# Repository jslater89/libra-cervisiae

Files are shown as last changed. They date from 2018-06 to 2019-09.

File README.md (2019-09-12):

# Libra Cervisiae
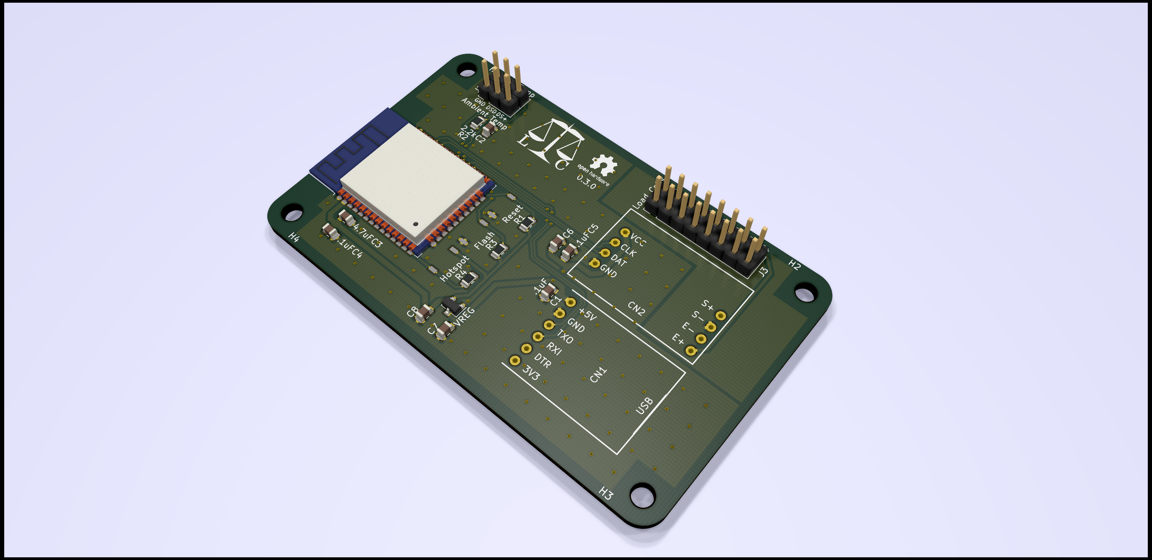
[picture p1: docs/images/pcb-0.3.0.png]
pcb


Libra Cervisiae is an ESP8266-powered microcontroller for reading output from a high-precision scale, used to weigh beer to measure the progress of its fermentation.

Development updates can be found at the project's [github pages site](https://jslater89.github.io/libra-cervisiae).

## History
Libra Cervisiae used to be Pendulum, which was itself once a tilting hydrometer (abandoned for patent reasons) and once a weigh-a-sinker hydrometer (abandoned for DIY difficulty reasons).

Libra Cervisiae has its root in experiments done in the 1990s on measuring fermentation progress by CO2 production, and more recent experiments done by forumgoers at [Homebrewtalk](https://www.homebrewtalk.com/forum/threads/estimating-alcohol-by-total-weight-during-fermentation.265716/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) and [Hobbybrouwen.nl](https://www.hobbybrouwen.nl/forum/index.php/topic,35958.0.html).

## Design
Libra Cervisiae is a microcontroller and PCB project. The project is designed with easy DIY in mind, and as such, the PCB uses large, easy-to-solder surface mount components, as well as breakout boards for the major, non-ESP8266 integrated circuits.

The project as specified here includes building a scale of your own, but the microcontroller's design ought to allow for hacking existing scales of the correct capacity, too.

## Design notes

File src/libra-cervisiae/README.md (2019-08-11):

## Libra Cervisiae
Source code for ESP8266 modules. Eventually it might support general Arduinos, through clever defines and whatnot. Today is not that day.

## Required Libraries
* ArduinoJson 5.13.2 (included in repository)
* [Arduino ESP8266](https://github.com/esp8266/Arduino)
* [DoubleMatrixMath](https://github.com/jslater89/DoubleMatrixMath)
* [HX711](https://github.com/bogde/HX711)
* [OneWire](https://github.com/PaulStoffregen/OneWire)
* [DallasTemperature](https://github.com/milesburton/Arduino-Temperature-Control-Library)
* [DoubleResetDetector](https://github.com/datacute/DoubleResetDetector)

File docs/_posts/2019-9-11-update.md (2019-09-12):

---
layout: post
title: PCB version 0.3.0 coming soon
---

assembled

Redesigning the board for the ESP32 was a good chance to make some larger design changes. The biggest, most obvious one is the rounded corners, along with the increase in size. This is to fit a specification, the Sick of Beige 80mm x 49mm board, for which I had hoped cases would be available. It appears they are not, but at least it's a spec I can design to.

This is the canonical simple 8049 case:

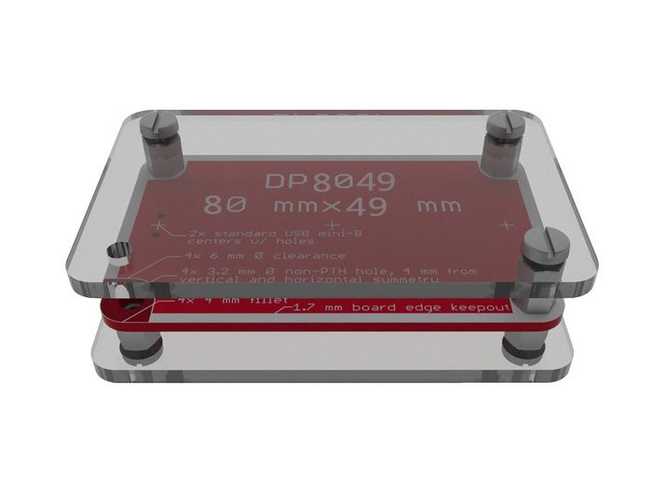
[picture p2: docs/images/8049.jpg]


Seeed Studios used to sell them for $3, but they're out of stock now. I'm sure I could find someone to knock out the top and bottom plates for me; it's not at all a complicated job.

The next design change flows out of a desire to support cases in the future: 90-degree pin headers (not pictured). The temperature sensor pin headers move to the same edge of the board as the load cell headers.

I added a third button to force a boot into hotspot mode, rather than doing a double reset detector. The only way to do that on the ESP32 would be to use the internal flash, and I don't want to do any more writes to the flash memory than I absolutely have to.

Lastly, I changed the trace routing somewhat, favoring straighter lines, smaller runs on the bottom layer of the board, and thicker power traces.

I expect this revision of the board to be the basis for 1.0.0. A future 2.0.0 might eliminate the breakout-boards-on-pin-headers paradigm altogether and go full surface mount. That would open the door to full assembly in one of the overseas shops, since there's no longer a tricky two-step process. It would close the door to all but the most dedicated hobbyists, however; it may be possible to keep both versions of the board around at the same time.

A final revision might be to use the Raspberry Pi's board dimensions instead, which would then open up a whole world of cases. It is notably less simple than the 8049 spec, however.

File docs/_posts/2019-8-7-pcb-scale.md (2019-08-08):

---
layout: post
title: A happy PCB update!
---

It's been a long time since I had real progress to report, but here we are: an assembled Libra Cervisiae PCB is actually reading from a load cell.

The problem is not one of design, at least for the single load cell case, but rather one of connectors. The latest revision of PCB uses standard 2.54mm Dupont connectors to attach the load cells. The load cells, however, come with very thin wires, and don't make good contact inside the terminal. I expect this can be solved by stripping a little more of the wire and folding the exposed part under the insulator before crimping. If that doesn't work, I can always try putting a little dab of solder in the terminal.

To verify it was the connectors after all, I ensured that the load cell was making good contact by getting the load cell wires in direct contact with the openings on some Dupont jumpers:



The PCB is performing well—using big pours for the excitation and signal grounds, and paying attention to return paths, seems to have made the miniature scale pretty interference-free. It's precise to within about a gram, or about 150 nanovolts. Fun.

Slightly less fun is that there are a few grams' worth of error depending on which of the four hookups the load cell is attached to. It might have to do with traces of slightly different length and therefore slightly different resistance. I might fatten the + traces up a bit to try to mitigate that, but at the same time, the use case here doesn't require perfect accuracy every time. We are, after all, basically integrating for better accuracy over the entire course of fermentation.

Anyway, having sussed out the issue, I can keep on pushing the design forward and get back to work on the full-size scale.

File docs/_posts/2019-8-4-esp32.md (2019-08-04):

---
layout: post
title: Getting back to work
---

I haven't done much on this project for almost a year—that's life, sometimes. I was planning on returning to it this summer anyway, but that return was somewhat delayed by some projects around the house, including (helpfully for this project) moving brewing operations from my friend's kitchen to my basement.

The latest piece of news is that I'm planning on switching from the ESP8266 to the ESP32. The big upside to this is that the ESP32 has enough memory both to load the scale program and do SSL requests, unlike the ESP8266, which means that the ESP32 version will be able to log updates directly to Google Sheets without an intermediary. The circuit design is a little simpler, too—the reference circuit indicates fewer pullup resistors, because more of them are on the module (the ESP-32-WROOM or pin-compatible ESP-32S). In exchange, it's a bit harder to solder—it's about the same size, but has more pins with finer pitch.

An ESP32 development board and a few bare modules are on their way from China. Once they arrive (September or so?) I can start on the process of updating the software and ensuring my board design is correct. In the interim, I hope to use the ESP8266 boards I have, along with the one-cell test scale I used last summer, to start isolating the problems with the full-size scale, which could be one of several things:

1. Bad crimps on the connectors on the load cell wires.
2. Bad soldering on the pin headers on the board.
3. Bad load cells in the full-size scale.
4. Poorly matched load cells on the full-size scale, such that their output is invalid when they're wired in parallel.
5. Incorrect understanding of how to wire load cells in parallel. I'm using four-wire full-bridge sensors, and simply connecting the excitation and sense lines in parallel is supposed to be enough, as far as I can tell, but I could be wrong.

Updates to come as I make progress.

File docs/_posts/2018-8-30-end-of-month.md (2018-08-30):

---
layout: post
title: PCB assembly and other development news
---

assembled

There you have it! An assembled Libra Cervisiae PCB.

After some head-scratching and trial and error, it even works—it's sitting on the table next to me, running the Libra Cervisiae software and playing hotspot. There are some caveats. We'll come back to those.

There was a good bit of trial and error involved in getting the build settings right, but I have a good set of them now. I'll be sure to add those to the manual when I get around to it.

I upgraded my Arduino IDE to 1.8.6, and upgraded the project structure to be one Arduino sketch file (libra-cervisiae.ino), and a bunch of C++-compatible headers and source files. This is better for organization, permitting actual, proper control of variable scope and whatnot, and doesn't depend on arcane features of the Arduino IDE pre-build munge-tabs-together step. Improvements all around.

There are several problems to take care of. First, I had some issues with booting into UART download mode, which went away after a bit of reworking. Either I had bad solder joins or a short between GPIO15 and GPIO2 (fixed by adding some solder and hitting it with the hot air rework thing to make sure it reflowed correctly), or the 10k pulldown resistor was too large. (I swapped in a 1.2k resistor at the same time as I did the other rework.) I can verify which one it was by switching back to the 10kohm resistor, which is planned for this evening. I'd like to keep the 10k resistor, because that's one fewer distinct part to include.

I had some trouble with resets until I checked the schematic and saw that I had the scale's clock and data pins backward, which caused hangs and resets. Now that that's squared away, I'm on to other troubles with sensors, namely that the on-board temperature sensor isn't showing up, and that there seems to be quite a bit of noise in the weight sensor readings, and that it looks to be drifting fairly substantially over time as I check back in on the output through the course of my work day, from about 1650 up to 1950 now in raw output. It may have to do with static, capacitive coupling, or board heating, or possibly noise from the CP2102 board. It's hard to say without an oscilloscope.

For the temperature sensor stuff, I have a few things to try—verify a temperature sensor on a breadboard, try plugging one in to the socket on the PCB, use a stronger pullup resistor. For the weight sensor, that's a bit trickier. I'll probably add a second, smaller filtering capacitor next to the HX711, and throw in more filtering near the ESP8266 for good measure. I may also add an analog ground plane to the bottom of the board on the corner with the load cell, to allow for a cleaner ground for the load cell's S- lines. In doing so, I can probably also eliminate vias altogether on that part of the board, and may be able to match trace length a little more closely.

Anyway, that's the state of things. Still moving forward, but PCB changes and debugging are harder and slower than doing it all on breadboards with pre-built boards. Stay tuned.

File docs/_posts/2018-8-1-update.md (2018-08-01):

---
layout: post
title: Update and further testing results
---

I've been hard at work the last few days. Let's take a look at what I've been doing.

### Development update: front end
Libra Cervisiae requires a more complicated user-facing interface than Pendulum did. In particular, calibration is more complicated, and the use of two temperature sensors (one for the wort, one for the ambient temperature) means there has to be some mechanism to select between them.

load cell calibration

To calibrate the scale, you start by hitting the tare button with nothing on the platform. That sets the zero point, as you'd expect it to. After that, you place a known mass on the platform, enter its weight in grams, and hit the calibrate button. That sets the scale factor, by which the raw reading is divided to obtain the output in grams.

Both tare and calibration have a seconds box; that determines over how long the value is averaged. 10 seconds seems like a good middle ground between speed and accuracy. Up to 30 seconds is supported.

temperature selection

The DS18xxx series of sensors have factory-set 64-bit device addresses, and can be connected in parallel on the same bus. Setting a wort sensor and board sensor allows me to provide accurate wort temperatures and also accurate ambient temperatures to correct the load cell output (if needed; see later on for that).

### Development update: back end
On the non-user-facing front, I've completed and committed a first pass at using Karl Balling's findings to interpret the scale's output. In 1843, that august German scientist determined that fermenting one gram of sugar yields 48.39% alcohol, 46.27% carbon dioxide, and 5.32% yeast biomass.

So, what we do is save the starting mass and the starting gravity when starting a batch. With the starting mass, we can determine the weight loss, and with the weight loss, we can determine the amount of alcohol produced. Since we're measuring the current mass of beer to get that weight delta, we can calculate the percentage alcohol by weight super-easily.

From there, it's fairly simple math to estimate an ABV figure and a specific gravity figure. Unfortunately, the gravity calculation depends on the ABV calculation at present. It seems to me like it should be possible to relate ABW to gravity directly, but I don't have a formula for that, so for now gravity will have to suffer compounded errors.

### Ongoing testing
At present, I'm testing load cell temperature sensitivity. You can follow my progress [here](https://docs.google.com/spreadsheets/d/1EILO6htwgF6LxLi3L6NfOGqo-U_QoY3HwP26hiXqwsg/edit?usp=sharing). The spreadsheet isn't updating automatically; instead, I'm plugging in updated values every few hours.

The results so far seem to suggest that if there is a temperature effect, it's quite minor. At the same time, the temperatures in my basement have not fluctuated sufficiently to get a good feeling for whether temperature actually makes a difference.

At the time I'm writing this, the maximum value is 2737.706g, and the minimum is 2736.207g, for an accuracy of almost exactly ±0.75g. That corresponds to about ±0.0004 SG, and the signal-to-noise conditions only get more favorable when moving up to full-size batches. It's looking good.

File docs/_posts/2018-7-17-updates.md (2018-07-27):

---
layout: post
title: Evaporative cooling, PCB prototypes, and creep tests
---

Three bits of news for you.

### Evaporative cooling
We were already aware of the load cells' temperature sensitivity. What I did not foresee was the importance of cooling mechanisms beyond simple radiative and convective effects in the air. It turns out evaporative cooling, for instance, makes an enormous impact.

chart

That's the result of spritzing a load cell with room-temperature water. (It may also be partially a resistive effect, but I wouldn't think the curve would look like that if it were water interfering with the load cells.) The measured gravity dips by 40 gravity units over the course of an hour and a half, then recovers over the next four or five hours to the initial point. Evaporative cooling, the same fundamental principle that makes sweating work, explains this well: linear cooling as the water evaporates, followed by a logarithmic approach back to the ambient temperature.

Is it going to be a problem in production? Time will tell. I suspect it won't be nearly as dramatic, in part because the load cell will usually be dry, except following very high krausen or blow-off, and in part because the temperature and humidity inside the fermentation vessel seem likely to be more or less inconducive to evaporation.

Another option would be moving the sensor out of the fermentation vessel, where we can control the conditions a bit better, but that has a few problems: first, it gets much closer to the BeerBug patent, which I'm trying to avoid; second, it requires designing an airtight enclosure for the sensor, and third, it needs some way to mount an airlock without allowing contamination inside the sensor enclosure. Those are difficult design problems.

### PCB prototypes
I went ahead and ordered some prototypes of the Pendulum PCB.

copper

Just look at that gorgeous copper layer. Anyway, those should get here in 2-3 weeks, along with the rest of the parts required to put it together. This design is not ideal if I have to switch to the fermentation vessel scale approach, but it should be versatile enough that I can at least make it work.

### Creep tests
Early on, one of my concerns was creep—the change in sensor reading over time when a load cell has a heavy weight placed on it. It appears those concerns were mostly misguided. After adding temperature compensation, the creep is very minor at the scale we're looking at. 20% of the full-scale weight seems to yield about 0.002 gravity points' error, which can probably be corrected for.

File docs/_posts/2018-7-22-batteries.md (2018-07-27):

---
layout: post
title: Libra Cervisiae, creep profiling, and batteries
---

I've come around fully to the Libra Cervisiae idea, given past experiments at [Homebrewtalk](https://www.homebrewtalk.com/forum/threads/estimating-alcohol-by-total-weight-during-fermentation.265716/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) and [Hobbybrouwen.nl](https://www.hobbybrouwen.nl/forum/index.php/topic,35958.0.html). As I alluded to earlier, I don't think there are that many design challenges to be found here. I do have one software thing to think about, and one battery thing to think about.

### Creep and compensation
Creep, the characteristic of load cells to drift to a higher reading when a heavy load is placed on them, might cause some error worth correcting for. According to the datasheet for my load cells, they have a creep response of 0.03% of the full-scale reading over the first five minutes. These are 10kg units, so that's a creep of about 3 grams. For the planned four-cell design, each cell takes a quarter of the load and sees a quarter of the weight delta; that's 4.75g per gravity point.

Still, the creep response might be greater than the datasheet suggests; it'll be worth experimentation as I get closer to a completed design. If I do need to worry about creep correction, I have in mind a little creep calibration process: set the scale up with a fixed weight on it and start a profile run. The scale logs half an hour's worth of data to come up with a creep curve for the first half-hour and a linear creep compensation factor for the time thereafter. Bob's your uncle.

In terms of implementation, the creep curve is probably only worth doing in always-on mode. Besides writing to flash—a limited resource—there's not a good way to keep track of time-since-start in sleep-and-wake mode, and if the interval is half an hour, it would be using the linear creep compensation factor on the first wakeup anyway.

### Batteries
Since the controller is part of the scale and therefore rests on the ground, there's no real need to keep the battery on the inside anymore. As such, I think the right move is to skip the battery-on-board altogether, and recommend external USB power of some kind.

Wall power is easy, as is battery-only power; USB power packs are easily available. Even assuming the worst-case scenario, that the CP2102 breakout board will always run the CP2102 in high-power mode, a 10000mAh battery pack will still run the board in sleep-and-wake mode for three weeks, and a 27000mAh pack will run it for almost two months. A 27000mAh pack is probably good for a week of runtime even in always-on mode.

Wall power with battery backup is a bit trickier; only a subset of the USB power packs out there support passthrough power in the way we're looking for, switching back and forth from wall power to battery power as needed. Such products exist, evidently; RAVPower and a few other brands on Amazon have reviews saying as much. Some other products briefly cut power output when switching from AC to battery. Of course, even if power cuts out briefly, it isn't the end of the world; after the end of the half-hour creep compensation period described above, it should be entirely possible to get consistent readings after reboot and continue to send accurate data.

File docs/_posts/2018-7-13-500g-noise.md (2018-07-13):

---
layout: post
title: 500g noise testing result
---

annotated-chart

Quick one today. Here's an annotated chart. You can see the effects of my programmable thermostat—the basement temperature stabilizes at about 11pm on the 11th, as the thermostat goes to nighttime temperature, then gets all jumpy again on the afternoon of the 12th, as the air conditioner kicks back in.

At the first arrow, I enabled temperature compensation, having recalibrated the test rig to read against an output range of 9000 (that is, the range to be expected with a 500g load cell and an 8.5g weight delta). The second arrow shows the typical noise—the line is much more wobbly than previously, oscillating within a range of about two gravity points.

There's a large jump in noise before the fourth arrow, but that's because I was working on something else at the workbench, and merely bumping the bench is enough to register. The even larger jump at the fourth arrow is because I was playing with the test rig, and didn't notice until some time later.

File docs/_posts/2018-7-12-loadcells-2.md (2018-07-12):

---
layout: post
title: Ongoing load cell testing
---

For once, I'll put the conclusions above the fold. First, testing has convinced me that 25x150mm or 27x150mm is the right size tube. Given the cantilever-style mount, measuring more precisely than about 0.07 grams seems ill-advised. Second, the ideal cylinder mass seems to me to be about 100 grams, so that the observed weights (for a 27mm cylinder) are on the order of 10-20 grams across a 1.000 to 1.100 gravity range. Third, even the 500g load cell is probably too large a range, and I think a 200g cell probably hits the sweet spot. Finally, temperature compensation for the load cell is going to be a necessity.

And now for the detail!

### Volume
The volume of the cylinder directly determines the weight change per gravity point. The bigger the cylinder, the more it displaces; the more it displaces, the larger the mass of the displaced liquid for a given density. For an 85cc volume (just about the volume of the 27mm cylinder), one gravity point difference in the density of the liquid means a difference of 0.085 grams. That's a little under three times the weight of a single grain of long rice.

To put it another way, the entire range of measurement is about as much as a US quarter and penny, or a single two-euro coin. These are extremely fine measurements, which I expect are already pushing these inexpensive sensors to their limits. Going much finer seems like a bad idea.

### Cylinder mass
The mass of the cylinder is less important, except in that it may affect the load cell's response because of hysteresis and creep effects. (Hysteresis means that the reading for 50g is different if the baseline is different; reading(50 - 0g) is different from reading(100 - 50g). Creep means that, given a constant load, the reading changes over time.) That's why I want to keep the mass low: a 100g, 85cc cylinder puts a load of at most 15g on the load cell when in use. On a 200g cell, 15g should be light enough to avoid creep effects. Calibrating in water will avoid hysteresis affects.

### Load cell rating
The 500g load cell works fine to measure a 20-gram range, which happily corresponds to about 20,000 load cell output units. The maximal moment-to-moment noise of about ±50 (over two-second readings) seems sufficiently low that going to an 8.5-gram range (8500 units) would also work. That said, a 200g load cell with an 8.5-gram weight delta would hit the required sensitivity with roughly the same output range as the 500g load cell and a 20-gram weight delta. The noise goes from about 1.1% of the output range to 0.4% with the smaller cell.

I'm running an experiment now with the 500g cell and an 8.5g weight delta. Temperature-corrected readings range from about 1.0565 to 1.058. 0.0015 isn't bad as error goes, but it's still unnecessarily high, and leads to an amplification of the temperature effect (a percentage of the cell's capacity, not the reading).

### Temperature compensation
Test run from 7/9/18, 20,000-unit calibration range with 1.097 actual reading, 20g weight, sans temperature compensation (gray line gravity, red line temperature):

chart1

Test run from 7/10/18, 20,000-unit calibration range with 1.065 actual reading, 20g weight, with temperature compensation (gray line gravity, red line temperature):

chart2

To make the results even more dramatic, when the 7/9/18 line smooths at the end of 7/10/18, that's when I was testing temperature compensation. Happily, load cell temperature response appears to be linear. Less happily, on the scale we're interested in, temperature response appears to be a little under three gravity points per degree Fahrenheit with a 500g load cell, or closer to one gravity point per degree Fahrenheit with a 200g load cell. Temperature compensation, then, is going to be very important. Hopefully it's similar across load cells of the same design, so that I can set a factory parameter that's close enough for most Pendulums.

### Next steps
I've been using the github Projects boards to organize my tasks. On my list while the 200g load cell is in transit:

1. Build a stopper assembly. Eventually, I want to have stoppers with holes just the right size for whatever the hanger ends up being, so that friction is the main thing holding it in, and the glue is just for stability. This one's going to be a little more provisional; I'm just going to squirt hot glue down the hole with the wee hex wrench and hope for the best.
2. Make a 100g sinker sized to fit in a growler or perhaps a gallon milk jug. That'll be my test rig for an actual fermentation. (Granted, most likely a fermentation of sugar water using baker's yeast, but you go to war with the army you have.)
3. Do some work on the software, and in particular the hotspot mode webpages. Mainly, I want to break calibration and configuration out into separate pages, so I can go into a little more detail on calibration, perhaps add a temperature calibration thing, and organize the configuration page better.

### Other items
If, for some reason, the weigh-a-sinker system doesn't work out, I hit upon the idea of weighing the entire fermentation vessel. Given an initial gravity, you get a fairly precise measure of volume in the fermenter, and you only have to measure a 5-gallon batch to within 20 grams or so to get a resolution of one gravity point.

I might pursue that one separately, or after this project has gotten to an acceptable state of completion.

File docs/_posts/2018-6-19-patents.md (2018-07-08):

---
layout: post
title: Patents and paths forward
---

So, I've been informed that the people behind the Tilt hydrometer have a US patent on the concept, so that's out the window. C'est la vie. If it weren't a good idea, it wouldn't have been worth pursuing or, indeed, patenting.

Ever onward, though! We are creative folk, and surely we can figure out some way to take the same measurement.

### Wireless floating hydrometer
The patent covers tilting hydrometers in particular, not wireless floating hydrometers in general. If you build a tilting hydrometer without the tilt, what you get is an ordinary hydrometer. The trouble then becomes detecting the liquid level. There's a perfect sensor for this, manufactured exclusively by Milone Technologies: a long resistor-tape whose resistance varies based on the depth to which it's immersed in liquid. It even comes with a food-safe enclosure and a premade connector.

#### Pros
* We don't have to redo very much work; we can just remove the GY521 and add a connector for the resistor.
* It probably simplifies the circuit design somewhat, although I'll have to set up two separate circuits going into the ADC.

#### Cons
* The water level sensor is $50, and none of the other options are nearly as good, or even solid-state. Cleaning a float sensor would be a huge pain.

### Wired sinking hydrometer
Hydrometers are devices which _read_ specific gravity, but _measure_ buoyancy. That's what your average hydrometer does: measures the difference between a reference buoyancy (namely, the hydrometer's neutral buoyancy) and an observed buoyancy, when the observed buoyancy is greater than the hydrometer's neutral buoyancy.

Is the direction of that inequality important? In fact, it is not, as my brewing partner observed. Equivalent to the floating hydrometer is a sinking hydrometer, where the observed buoyancy is _less_ than the hydrometer's neutral buoyancy.

Say you have a sinker which masses 50 grams and occupies 20 cubic centimeters. (I have no idea if these are realistic numbers. I'm only using metric because it's convenient for water mass/volume.) It displaces 20ccs/milliliters/grams of 1.000-gravity water, for a net weight of 30 grams. If the liquid's gravity is 1.100, the displaced liquid masses 10% more and the buoyant force is 10% greater; the net weight of the object is now 26 grams.

It's much harder for humans to pull on a string and say, "This weighs 26 grams," than to look at a scale on a float and say, "That's between 1.095 and 1.105." Crucially, though, it's easier for computers.

#### Pros
* Waterproofing becomes almost a non-issue. The only things going in the carboy are an aluminum load cell with insulated wires and an entirely inert sinker, and only the sinker actually goes into the wort. (A separate temperature sensor float might, too, but could be designed to be permanently sealed.)
* The microcontroller/PCB no longer needs to fit into the cylinder, which opens up room again for using the Wemos dev board. (I'm still going to make the PCB, though. It's cool, and without having to hit the 20mmx70mm target, I can make it user-friendly, with molex connectors for the various sensors.)
* May actually be more accurate than the tilting models, given that it could easily be sized to hang between the trub and krausen.
* No longer depends on battery power or indeed an ESP8266-compatible microcontroller.

#### Cons
* A bigger departure from the initial concept.
* More difficult to sanitize.
* Requires a specially-modified stopper.

### Conclusions
Ultimately, the guiding light for this project is cost, followed closely by ease of assembly. I think the wired sink hydrometer is definitely the way to go.

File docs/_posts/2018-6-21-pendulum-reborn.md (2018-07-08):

---
layout: post
title: Pendulum Reborn
---

### The Redesign
pendulum2

Pendulum is dead; long live Pendulum! As you can see, it's gotten much bigger: 64mm by 43.2mm, to be exact, and the ESP8266 antenna sticks out another 6mm. Since the PCB no longer needs to fit inside the carboy, I have a lot more room to work with.

If you haven't checked the README lately, that tidbit might come as a bit of a surprise. Since the tilting hydrometer is patented, we to come up with something else. Pendulum now operates by weighing a sinker hanging into the wort. The observed weight corresponds directly to the specific gravity.

pendulum2diagram

I used the extra space now available to me to add a ground pour on the back of the board, as well as to move all components to the front of the board. (If ever there's a factory-assembled version of Pendulum, that makes it cheaper.) I also moved R6 around the corner of the ESP12, in the dead space between the TX/RX lines and the HX711, to make the soldering a bit easier between SW1 and SW2.

One thing I still need to find out is whether the TP4056 boards power OUT+/- even if there's no battery. If not, there's a little more design work to be done, probably with the USB lines feeding the voltage regulator directly, and the OUT+/- lines connected to them via diode.

pendulum2schematic
_I just noticed now that I had failed to connect GPIO16 to RST. Oops! That's fixed._

The GY521 has been replaced by an HX711 breakout board, which handles reading from the load cell. There's also provision for a TMP36 or TMP37 sensor. Since that's a second analog sensor and the ESP12 only has one ADC pin, the two sensors are both wired to it, isolated by diodes. The temperature sensor is powered by the SENS2 GPIO, while the SENS1 GPIO controls a transistor which opens or closes the battery monitor circuit.

Notably, every single GPIO on the ESP12 is now in use. That's quite something.

### The Stopper Assembly
Getting the load cell into the carboy is going to present some interesting challenges. All of the cheap ones of which I'm aware are beam-type sensors, which read based on the bend in a long (on our scales) bar. I have a few on order, between 40mm and 60mm from end to end, with (ordinarily) threaded mounting holes. There are two ways I think we can go about doing this.

method1

Make an L shape with threaded rod as the riser and the load cell as its base. Attach the sinker to the end of the base. Tilt it into the carboy neck. I think this method is likely to read with more precision—there's more torque on the load cell, which is what we want, and smaller variations in the observed weight of the item will yield larger deviations in the sensor's output.

method2

Use an L-bolt to hang the load cell by its top mounting hole, and make a second, smaller L with a piece of threaded rod. Attach the sinker to that. This is most likely to fit into the carboy without any drama, but may not read as accurately—the flex of the L-bolt and the threaded rod may throw things off. Then again, they might not be long enough, or the sinker might not be heavy enough, to notice.

### Progress
I have a few load cells on the way, rated for 500g, 750g, and 1kg. Once they arrive, I'll be able to start experimenting, both with the mechanical design and the code. Until then, there won't be much to say.

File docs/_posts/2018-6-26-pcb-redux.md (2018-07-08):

---
layout: post
title: More on PCB Design
---

## On the implied pun
1.0.0-rc.5

Moron PCB design would be an adequate title for this post, too. I'm a software engineer by trade. Going from a world where there's just 'true' and 'false' to a world where there's 'on', 'off', and 'maybe somewhere in between?' has caused me no end of trouble.

In this iteration, the ground pour has expanded even further, to hit pretty much every ground pad on the board, which I guess is what you're supposed to do anyway. There are more capacitors, one to filter the USB power input, and one to filter EMI from the battery monitor-to-ADC trace, both changes made based on feedback from r/PrintedCircuitBoards again. They're great folks.

There's also a functioning battery disconnect circuit, which uses the USB+ line to pull a p-channel MOSFET gate high, therefore cutting off the battery from the circuit. It's buffered by a 47uF capacitor, which hopefully will provide enough oomph to handle switching. I'd aimed to do something like this on my own, but ended up copying a circuit from the Arduino forum, which fixes some faulty assumptions of mine and correctly isolates both the battery from the USB voltage and the MOSFET gate from the battery voltage.

Generally, though, if you've been following along, the board has been changing less and less between updates. I think I'm getting close to a final design, one I can send off to a fabricator for some prototype production.

## Board production
1.0.0-rc.5

Now that a board design is close, I think it's time to talk a bit about production.

### Version numbering
Repository watchers may have noticed version numbers counting up. I figure I'll maintain two sets of releases: pcb-x.x.x-prerelease.x for PCBs, and esp-x.x.x-prerelease.x for the software.

For the PCB, I don't see much use in distinguishing between alpha, beta, and rc. All pre-production boards will be rc.x boards. The first board I order will be 1.0.0. Any required design changes will be part of 1.0.1-rc.x, and the second hardware revision will be 1.0.1. Functional changes will bump the middle number, and redesigns will bump the first number.

The software versioning will be a little more ordinary, starting at 1.0.0-alpha.1 and counting up as you'd expect.

### Near-final bill of materials
Now that the PCB design is nearly finalized, so is the [bill of materials](https://docs.google.com/spreadsheets/d/1zar1gR90osImwsAmGcO47G6zN50gNiWxno9D_cdoG40/). The electrical components come to $11.64 per board, if you can buy in bulk, or a lot more than that if you can't. Mechanical components and a plastic enclosure represent another $5.36.

Most of the parts, and all of the electrical components, are sourced from AliExpress. With the exception of the standoffs and screws for mounting in the enclosure, the mechanical parts all come from Amazon.

### Things for sale
There's a little problem with the bill of materials. One PCB costs $11.64, but requires you to buy $55.85 worth of parts. Wastage for the other categories is equally pronounced. I hope to benefit both people who want a Pendulum and, to a degree, myself, by passing on most of the savings from bulk purchasing by selling kits, and maybe even assembled boards.

In both cases, I believe that puts me under the FCC's regulatory authority for unintentional RF emitters. (Kits are a bit of a gray area, but kits intended to be assembled into a specific final product are less so, and assembled products for sale are literally the opposite of a gray area.) Because that's a significant startup expense (amount to come; I'm getting in touch with a local EMC testing house), I plan on running a Kickstarter to help defray the cost, in addition to the cost of some other tools which will help with assembling boards.

To reiterate, that's still some time off. I'm still waiting on the load cells and temperature sensor, and before I get into working out the PCB prototype, I want to get the coding done, along with the stopper and load cell design. For both tasks, I'll still be working against the same development board I've been using. Given the lesser physical constraints on this project, you can probably figure out how to do the same, if you want to follow along.

Once I've established that everything works with the dev board, built a load cell assembly which fits through a carboy neck, and hand-soldered the first Pendulum PCB prototype, then it's probably time to get into a production kind of mindset.

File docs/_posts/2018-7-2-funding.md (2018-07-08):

---
layout: post
title: Certification, funding, and electromagnetic compatibility
---

### Certification
I heard back from the local EMC testing lab today; their quote of $1350 for the required unintentional-radiator testing is broadly in keeping with what I'd expected. Lacking testing doesn't limit my development work, or anyone's ability to assemble a Pendulum on their own. All it does is prevent me (or anyone) from selling full kits or assembled versions until someone does the testing work.

### Funding
I can't really absorb that kind of cost, so absent a mysterious benefactor, it's going to take some crowdfunding down the road if I want to sell kits, partially-assembled kits, or fully-assembled projects. I think it's probably worth a shot at a Kickstarter. It isn't a very big ask for what it is. Eventually, I'd like to have a little Etsy shop or something, where I can sell kits and assembled boards on an ongoing basis, and perhaps fund a second revision which is designed for professional assembly. (That scales a whole lot better than me paintstakingly assembling things by hand in my basement workshop.)

Exactly how big an ask? I've been playing around with a spreadsheet to figure that out. Assuming I very approximately double my cost of materials for the backer rewards which are actually Pendulum units, between 60% and 70% of the Kickstarter haul goes to fees, taxes, and materials costs for reward fulfillment. If I take in about $4000, the Kickstarter haul covers the certification cost. If I take in $5000, it covers certification and some tools to make assembly a bit less blindness-inducing.

Of course, both of those only pay for one round of EMC testing. It's entirely possible that the board will fail the first round and have to go back in after a redesign, for another $1350. That's obviously something to be avoided, but a Kickstarter banner number of about $8500 gets me tools plus two rounds of testing.

To get those numbers, prices start at $35 plus shipping for a completely unassembled PCB-only kit, up to $70 plus shipping for everything fuly assembled. Those prices are higher than what I want to charge once I've gotten off the ground; they have to be a bit inflated at this stage so I can manage the setup expenses.

### Electromagnetic compatibility
board-again

So, that means another board change. It looks dramatic, but isn't really. Mostly, what I've done is aimed to route traces on the top layer as much as possible, to avoid breaking the ground plane on the bottom in as many places as possible. I think I succeeded pretty well. Now, only the HX711 CLK and DAT lines, the HX711 power line, the battery monitor ADC line, and some USB power lines dip down to the bottom plane, and only then to cross under pads and other traces. You can see all the breaks in the ground plane in the image; anywhere inside the board with a black background has no copper on the back plane.

I also added front ground pours and stitching vias, in part for mechanical stress/flexing reasons, and in part because I was advised it would make for less noise on the various lines and less EMI in general.

Several times now have I said, "I think this is a final design." I think that again this time, but of course you can't trust me on that front. Regardless, I still have some time. The electronic components I need for Pendulum v2 are still in transit, though now they've left China and are making their way to the US postal system. Once they're here, I can start on the next iteration of the software; once that's ongoing, the news here will largely shift in that direction.

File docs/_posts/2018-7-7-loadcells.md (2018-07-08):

---
layout: post
title: Load cells and initial results
---

cells

My load cells arrived on Thursday, so I took a few minutes to solder the headers onto the HX711 breakout board, wired everything up, and tried a few things out. Initial results were promising: although the load cells aren't hyper-sensitive, they do seem to have pretty decent performance, and the measurements via the HX711 are low-noise and consistent even at the 128x gain setting.

Before I get on to last night's test results, it's time for a little math interlude. All of the load cells I obtained have an output rating of 1 mV/V at their rated capacity. So, the 500g cell I'm testing with, if fed 3.3V, will provide an output of 3.3mV when loaded with 500 grams. The thing is, we're not interested in measuring 500 grams. Really, we're interested in measuring something between one tenth of a gram and one third of a gram. 3.3mV over 500 grams is 6.6 microvolts or 6600 nanovolts per gram. That means 660 nanovolts per tenth-gram.

The HX711 documentation says that its input noise is 90 nanovolts in 80Hz output mode; assuming we don't add too much noise on the PCB or via the wires from the sensor to the PCB, we've got much more signal than we do noise. We also have the option of soldering across a pad to go to the lower-noise 10Hz output mode, but I don't think I'm aiming to do that unless it turns out to be necessary.

Anyway, some playing around with a growler (whose neck is somewhat narrower than a carboy neck; it's good to over-engineer) suggests that the L-shaped tilt-it-through method is untenable. I'll try it on the carboy on brew day tomorrow, but I think the cantilevered torque-type mount is the solution we'll be going with.

benchtop

So, I built one on my workbench and put enough nickels in a plastic cylinder to make a 65-gram weight, then tied a bit of thread around the cylinder and hung it from the end of the load cell assembly. I'm gratified to say that the results look promising. The sensor outputs a value of about 106000 without the weight, and 155000 with it, depending on the exact tilt. It also seems to be able to measure the weight of a short jumper wire, which weighs something like half a gram. I took a little [video](https://photos.app.goo.gl/Fzg2QcWucn6WXUmT7) so you can see it in action.

Taking 40 samples over two seconds (i.e., one sample every 50 milliseconds) with a constant weight, the difference between the maximum and minimum readings usually ends up being about 175-200. After the system stabilizes, each 40-sample read is within ±30 of a 20-second/10-read rolling average reliably, and within about ±50 at the outside.

One thing I have noticed is that tilting the sensor slightly (as in the pictures), instead of letting it hang vertically, yields better measurements—the force on the sensor does better at bending it, which is what the strain gauge ultimately measures. That may lead to a need for per-batch calibration—take an initial reading with your refractometer or hydrometer, enter the reading in the Pendulum UI. By comparing its reading with the entered reading, the software can calculate an adjustment factor. We'll see if it's necessary.

I also had to add a pull-up resistor to the PCB, because the temperature sensor requires one. (There are internal pullups on the ESP8266, but they're very weak and I don't think there's any harm in having one on the board.) That change is in the repo now.

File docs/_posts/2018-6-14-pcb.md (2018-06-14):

---
layout: post
title: A first-draft PCB design
---

board

I mentioned in the last post that a PCB is probably the way of the future, given the difficulty in finding narrow ESP8266 breakout boards, and soldering jumpers into through-holes is going to be at least as annoying as the surface-mount soldering the PCB requires.

KiCad files are now in the repository, so you can take a look yourself and critique my baby's-first-PCB design. Improvements welcome. Like I said in the other post, I'm going to have to build all of this on a breadboard first anyway, so if you know what you're doing and want to fix my mistakes, go right ahead.

schematic

Parts-wise, we have an ESP-12E/F, a GY-521, an MCP-1700 SMD voltage regulator, a TP4056-with-protection-circuit breakout board (the six-pin version), and a Sparkfun BOB-13263 serial interface.

The ESP-12F has the usual pull-up/down resistors on the pins you'd expect, with pushbuttons on RST and GPIO0 for resetting and flashing. (There is no auto-reset or auto-flash. I didn't think it was worth the bother; after all, this isn't a development setup.) R2 and R3 make a voltage divider to take 4.2v to around 1v for battery measurement. (It's actually .988 volts at full power.) If you don't like the idea of the 8-microamp drain, you can leave them unsoldered.

The ESP-12 still uses a GPIO to power the GY-521/MPU-6050. Nothing much has changed there.

The voltage regulator is an MCP1700, which has both low dropout and low quiescent current. Dropout in the range of 200 mV seems fine for this application, especially given the extremely low quiescent current draw. ~3.4v is very close to the end of an 18650 cell's life anyway. There's a 1uF capacitor for output smoothing.

The TP4056 is a traditional choice for this application, and the versions with discharge protection are an easy sell. The TP4056 has a USB port in addition to a V<sub>in</sub> line; the latter is connected to the +5V line on the serial board, so attaching a USB cable to either the TP4056 or the serial board will charge the battery. There are two options for battery connection: copper pads at the bottom corners of the board, and through holes for a 2-pin molex connector whose size I don't remember off-hand.

The BOB-13263 is a Sparkfun USB-Serial breakout board based on the FT231X. I've selected it mainly because it's small and doesn't come with any headers attached.

pcb

It's a hybrid board, of sorts: the resistors, switches, voltage regulator, and capacitors are surface-mount parts. The resistors and capacitor are all 1206-size, and the voltage regulator and switches are sized also such that the soldering is within the realm of the plausible for an amateur with an average soldering iron.

Besides the MCP1700, the other integrated circuits are on breakout boards (or an edge-solderable PCB, in the case of the ESP-12). This dramatically simplifies the soldering required to get the various chips onto the board.

The TP4056 and BOB-13263 both happen to be narrower than the PCB, and are mounted in the center (the TP4056 on top, the BOB-13263 on the bottom). The GY-521 placement is non-ideal, in that it actually pokes out beyond the edge of the board a bit. It's mounted on the bottom, opposite the ESP-12 and above the BOB-13263.

In all, the PCB with mounted GY-521 should be 21.3mm wide and 70.2mm long. I don't have a good number for how tall the package will be overall, but my suspicion is that it ought to be in the 12mm range. (Figure 3mm for the GY-521 and BOB-13263, 2.5mm of spacer, 1mm of PCB, another 2.5mm of spacer, and 3mm for the TP4056.)

That 21.3mm of width is concentrated at the level of the GY-521 and PCB, too; it's several millimeters narrower as you move upward, since the ESP-12 and TP4056 don't take up the full width of the board. It should fit readily in 23mm ID cylinders, and it would likely fit in 22mm ID cylinders.

At 70.2mm of length, there's room for a 65mm battery with 5mm to spare in a 140mm cylinder. All told, a handy little setup, and as far as I know, the smallest beer-monitoring setup out there.

This isn't my priority at present; first I want to prove the whole concept with the two-cylinder nunchuck hydrometer I have in mind. After that, we'll begin to look down the road toward the PCB.

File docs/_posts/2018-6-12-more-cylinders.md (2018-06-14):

---
layout: post
title: More news on the cylinder front
---

The 27mm outside diameter cylinders arrived, and unfortunately, they've caused more problems than solutions.

The first news was good news: the Wemos board, with the battery tray removed from the bottom, does indeed fit—barely—into these cylinders. I had to remove the threads—they're substantially narrower than the rest of the cylinder. Once I hacksawed the top off, leaving a straight-sided cylinder of roughly 130mm length, the microcontroller slid in without too much trouble.

Unfortunately, the 90mm board and the 65mm battery add to more than 130mm; they won't fit in one cylinder. That's a problem.

### What next?
Well, I have a few ideas.

#### Wired float
Build a wired float with the MPU6050 only, using a cable running out through the carboy stopper and to the microcontroller, which sits outside the carboy altogether.

This has a few benefits. It allows for infinite lifetime, since the microcontroller can be charged while the float is in the wort, and for high-power applications. The microcontroller could respond to HTTP requests with a JSON object containing a current reading, for instance, or display the current status on an LCD screen.

It also has some difficulties and drawbacks, primarily in cable choice. The cable literally has its finger on the scale. My testing this evening suggests that a very, very fine cable would be required to avoid weighing down or pulling up on the float. A standard USB cable, for instance, is right out.

Experiments did show, however, that a cable hot-glued through a stopper is sufficiently waterproof for this sort of thing.

#### Two-cylinder hydrometer
Use one cylinder to house the microcontroller and MPU6050, and a second cylinder to house a battery (or batteries). Connect the two cylinders with a cable.

The second cylinder would be big enough to fit a pair of batteries, for a really tremendously long lifespan. (On a single 2600mAh li-ion battery, the setup on my workbench has gone from 4.2 volts to 3.85 volts in eight days.) Although the battery cylinder would tug on the sensor cylinder, it would do so in a predictable and repeatable way. With the batteries pushed to one side of the cylinder by a well-designed sled, it would even roll-stabilize the sensor float, for better accuracy.

For this setup, I can put the MPU6050 near the bottom of the float, so that it rests under the surface of the wort. This is likely to improve the accuracy of the wort temperature readings.

I think this is the most promising; it doesn't rely on solving any currently-unsolved problems, with the exception of working out how best to fish it out of the wort. (I'm thinking probably hot-glue some fishing line to the bottom of the battery cylinder.)

#### Spliced one-cylinder hydrometer
Cut the necks off of two cylinders, and the bottom off of one. Splice them together to make a ~250mm cylinder. I gave this a try, and wasn't able to get a waterproof seal. I have plenty of cylinders to work with, however, so I'm going to keep at it. It would be the most straightforward bit of construction.

### Other options
While I'm nearly to a functioning setup, and one of the options above seems likely to work, I'm a little iffy about using these particular cylinders. They're a nonstandard size, and so far I've only found them in one place, from an Amazon retailer. That seems sub-optimal. It may behoove me to come up with a design that fits into a 25mm tube instead of a 27mm tube; the former is a standard test tube size and much more easily located.

#### Use a smaller development board
The Adafruit Feather HUZZAH is 23mm wide and 51mm long, with every feature found on the Wemos board currently called for. Given that the 25mm Wemos board fits into 27mm cylinders, it seems reasonable to hope that the 23mm Adafruit board would fit into a 25mm cylinder.

There's also an [even smaller ESP32 board](https://www.tindie.com/products/onehorse/smallest-esp32-development-board/), measuring a hair under 18mm across, but it's also handmade by a guy in California, and is correspondingly expensive. Also, if this project takes off, I'd feel bad subjecting him to a wave of orders.

#### Use a bare ESP12 and a custom PCB
Build a custom PCB designed to be user-friendly. Rather than solder on tiny surface-mount components, provide through-hole mounts for breakout boards. An ESP12, some buttons for flash/reset, a battery charging chip and voltage regulator, a GY521, and a serial interface on a PCB would be a reasonably easy soldering project for an amateur. I suspect it could be done in maybe 20mm by 70mm, likely with a bit of stacking of chips. Adding an 18650 cell, that leaves an excess of 15mm to fit into readily-available 25x150mm cylinders.

This is probably the best option, and leaves end users with the most latitude to fit it into various containers. It's also a bit down the road; I'm going to be exploring the options with the Wemos D1 board for now.

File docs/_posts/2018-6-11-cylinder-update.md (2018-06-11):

---
layout: post
title: Cylinder update
---

The first of two plastic cylinders has arrived. This is the 27mm inside-diameter coin collector's cylinder. The microcontroller just barely fits into it with the battery attached, but the cylinder appears to be a hair over 30mm wide, according to my measuring tape, too wide by about half a millimeter to fit into a carboy. I'll test for sure on the carboy next time I have a chance.

The 27mm outside diameter cylinders obviously won't fit the tube, but they're also 150mm long, and may be able to fit the battery and microcontroller in line, depending on how they can be angled inside. I'll give that a try when the smaller/longer cylinders get here.

In the event that neither setup works, I have still another idea, involving a modified carboy stopper, a cannibalized Ethernet cable, and a separate sensor float with the microcontroller outside the carboy and only the accelerometer inside. Updates as they come.

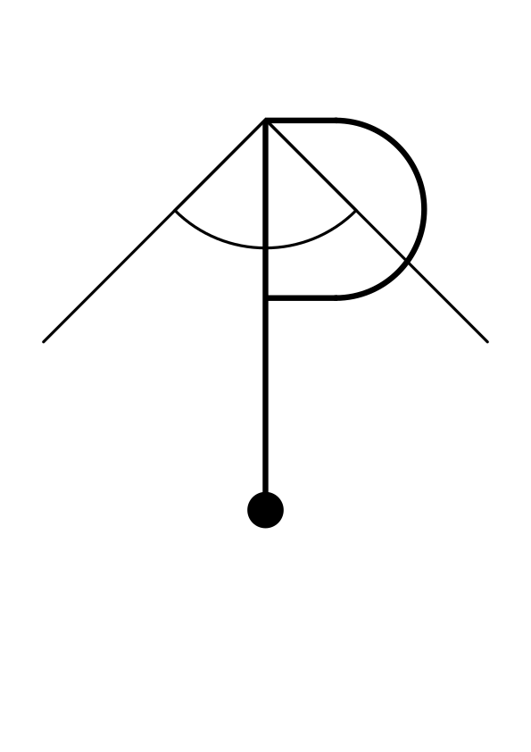
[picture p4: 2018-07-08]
docs/images/pendulum.png

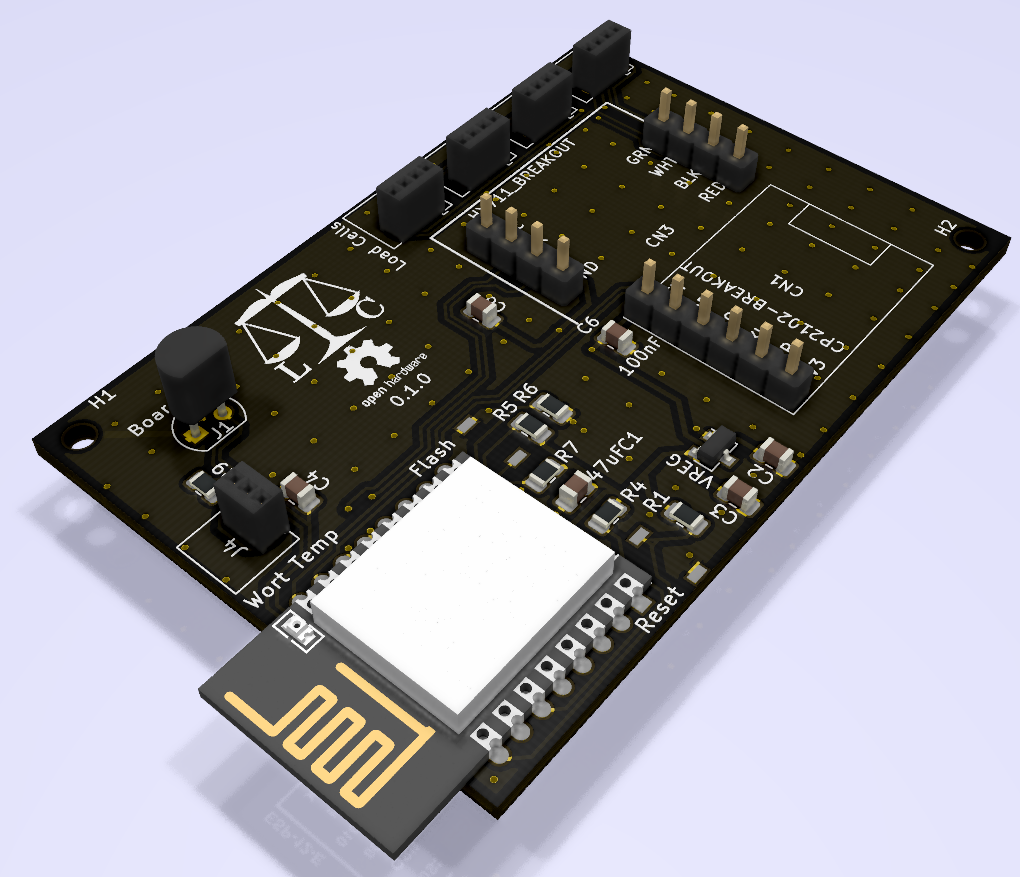
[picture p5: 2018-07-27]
docs/images/pcb.png

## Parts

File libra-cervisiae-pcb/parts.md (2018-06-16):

PCB shopping list

The board itself ($8/10pc lead free from JLCPCB)
http://www.digikey.com/short/j9mz0v ($14 incl. shipping, includes 1 extra of everything)

ESP-12E/F ($2 AliExpress, $7 Amazon)
TP4056+protection circuit (6-pad) ($1 AliExpress, $7 Amazon)
CP2102 micro USB breakout board ($2 AliExpress, $7 Amazon)

~$30 (AliExpress; 20-30-day shipping), ~$45 (Amazon Prime 2-day)

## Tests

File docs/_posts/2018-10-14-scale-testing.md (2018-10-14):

---
layout: post
title: Scale testing and current state of affairs
---

It took me a while, thanks to some [other projects](https://manywords.press/rpj-a-free-open-tabletop-roleplaying-game-system) I ended up focusing on in September-October, but I finally got a full-size prototype built.

top-off

top-on

inside

On the one hand, the mechanical design seems solid. The platform is 14" wide, which should accommodate any fermentation vessel under the 30ish-kg capacity of this load cell combination without much trouble, without being too large to fit into a fermentation freezer.

On the other hand, the electrical design has been causing me fits. Either I have one or more bad load cells, or my connector crimping is not up to snuff and I have one or more bad connectors, or I've been misled on the ease of [connecting load cells in parallel](http://www.marco-iw.nl/file/1355354080.2319WAfreS/2%20Loadcell%20cabling.pdf).

My present to-do list is four steps:

1. Write a scale-test function for the PCB firmware, which keeps the HX711 powered all the time and reads its output constantly, without much averaging.
2. Connect each load cell individually to the PCB via jumper wires or jumper wires+breadboard, and verify that each one works individually.
3. Assuming 2. shows four good load cells, re-crimp connectors for each load cell, perhaps with a dot of solder or a bit of solder paste, then verify that each load cell still works with the connector.
4. Reassemble everything and see what happens.

I'll report on my results as they happen.

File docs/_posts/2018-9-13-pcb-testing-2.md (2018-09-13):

---
layout: post
title: PCB testing, part 2
---

assembled

The 0.2.0 PCB arrived yesterday, and in between other things, I spent an hour or so assembling it.

All of the changes made turned out to be improvements. Below are two schematics, the old first, followed by the new.





The biggest difference is in the top right of the board. The load cell sockets have been replaced with a two-row pin header, compatible with ye olde standard Dupont connector. Dupont connectors are much easier to crimp with human-sized hands, and aren't significantly less secure than the miniature ones the previous design called for.

Furthermore, the ground plane no longer extends over the analog part of the board. The top pour is the S- line, and the bottom pour is the E- line; E+ and S+ are the traces on the top and bottom, respectively. The combination of shorter, more direct trace routing, low-resistance return paths, and isolation from the ground plane (which warms up as the board does) seems to have done the trick. The raw output noise appears to be in the range ±25-50, which is better than the breadboard version, and should represent an output error of about ±1g on a scale with a total capacity of about 30kg.

There are some other, minor changes, too; the temperature sensors are now both connected via pin header, and the board now has labels for which pin is which on the headers. There are more capacitors for smoothing and filtering, an extra 100nF unit on both the ESP-12 and the HX711. The mounting holes are no longer part of the ground plane, so that accidentally scratching the board there with alligator clips doesn't expose copper. Lastly, the schematic now calls for a 2.2kohm resistor on the DS18B20 pins rather than a 10k resistor.

So, the board pictured above will be the base of the first full-scale prototype, pending only the purchase of some plywood, some hardware, and perhaps some superglue, standoffs, and screws. We're in the home stretch now.

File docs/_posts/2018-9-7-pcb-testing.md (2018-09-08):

---
layout: post
title: PCB testing
---

After a week or so of PCB testing, I have some results, and a 0.2.0 PCB on its way from the fabricator.

The big news is that all the on-board sensors are working. After buying a crimping tool I decided to switch to pin headers and Dupont connectors. The 1.25mm pitch pins are super-hard to DIY-assemble.

More big news is that the software is now almost all working. The double reset detector wasn't, last I tried, but sleep mode has kind of fallen by the wayside in favor of always-on station mode. I'll debug it further as I have time, but it's down the priority list.

The other big news is that the board seems pretty sensitive to heating from the ESP8266, which runs pretty hot and warms up the entire board. The temperature sensor (now working, with the substitution of a stronger pull-up resistor for the data line) reads about 10F warmer than ambient, which appears to skew the HX711's reading somewhat. (It may be heating of the traces.) I'm hoping that the separate copper pour for E- and S- on the HX711 helps there. In the same vein, I switched the on-board temperature sensor from being attached directly to the board to being a connector for a cabled sensor, so that it can more accurately measure the temperature at the load cells.

The other major design task is considering what I want to do for an enclosure. Most of them are larger, which means the PCBs get bigger, which would, granted, be a good thing for heat sinking. The downside is more careful measuring and possible incorrect measuring, which makes the 

That's about all for now—I've been busy on other projects, and have had a few weekends in a row with just about zero time to sit down and code, so the groovyLogger changes aren't any further along.

If you're looking for a way to contribute, here are two items. (I've made issues for them. Comment on the issue if you want it.)

* groovyLogger CLI and/or relay-to-Google-Sheets, or other improvements.
* Fritzing diagram for the breadboard version, for the DIYers with full parts cabinets already.

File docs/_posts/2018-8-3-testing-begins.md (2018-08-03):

---
layout: post
title: PCBs and initial live testing
---

It's been a madcap few days with exciting news all around.

### Temperature compensation
graph1

The chart pictured above shows about 28 hours of output data, temperature in blue and weight in red. There's a clear relationship between the weight and temperature; as the sensor gets warmer, it reads a lower weight. There's another feature of note which is more clearly revealed by the graph with correction enabled:

graph2

This chart has data for about twelve hours, from the morning to the early evening. The big dip in temperature occurs when the air conditioner comes on in the afternoon. Note that the load cell output still reflects a change in temperature, at least at first. This is because the load cell responds more slowly to temperature than the temperature sensor. The sensor cools off, so the correction kicks in too soon. As the load cell cools down, the value returns to average.

The magnitude of the correction is -75 raw output units per degree Fahrenheit. That's about one-third of a gram per degree Fahrenheit with the single-cell scale.

### PCB arrival
pcb-front

The first-run PCBs have arrived! Unfortunately, they're no longer the state of the art design; fortunately, they should be sufficient to test the ESP-12 breakout portion, which is the one I'm most concerned about.

Testing indicates that somehow, I managed to get the pin spacing and board dimensions of the HX711 and CP2102 just about right. (I'm skipping the TP4056 module, since it's no longer part of the board.) It isn't perfect, though, so before I order the next revision of the board, I'm going to borrow some calipers and make sure I get the spacing and sizing just right.

In [this picture](https://i.imgur.com/ei60qSA.jpg), you can see the breakout boards in position. In [this one](https://i.imgur.com/Znatw0S.jpg), you can see the old but attractive logo.

### Test fermentation under way
testrig

In the most exciting news of the day, test fermentation has begun with a duct-taped temperature probe and an old protein powder jar. (Obviously, I'm not super-concerned about infection here.) I didn't think about it, but the weight sensor has some impact on equipment weight. Attached like this, it adds about 8 grams. Hanging into the fermenter through a thermowell, I expect it would add a good bit more—the weight of the sensor head plus the weight of the cable run. That said, it isn't crucial to calibrate it in. All it affects is the volume estimation.

I only mixed up the fermentation sugar-wort about three and a half hours ago at the time of writing. It kicked off at 10.2 degrees Brix/1.042 SG and 2379 grams. It's started bubbling, but not enough to affect the weight reading yet. I'll have more to report as it moves along (I hope!).

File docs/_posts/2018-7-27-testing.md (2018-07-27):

---
layout: post
title: Scale testing a scale
---

### Testing
scale

Libra Cervisiae has advanced from theory to prototype: I turned my 10kg load cell into a 10kg scale. Is it mechanically stable? Not as much as I'd like; that's why my plan for the final version remains a four-cell, four-point scale. Is it accurate? Yes, it appears to be sufficiently so.

I've said in prior blog posts that the required accuracy is about ±10 grams for a 5-gallon batch, because one gravity point on a 5-gallon batch is about 20 grams. This load cell is accurate to about ±2 grams. Even if the error when combining four cells is 100% cumulative, that yields an accuracy of ±8 grams; it should be accurate to within about one gravity point.

Currently, I'm testing for creep and temperature sensitivity. It would have been smart to write up a little script on my workbench laptop to log data there, but alas, I did not think of this until just now. Still, the output reading hasn't changed very much with either time or temperature, which I consider promising.

An interesting finding is that the weight of the plywood weighing platform alone isn't sufficient to load the cell enough for a stable reading. (As I understand, that's a common but poorly-documented problem with load cells.) Putting a 50-gram screwdriver on the platform fixes it. In the final design, I'll probably call for taping some nickels to the corners of the scale.

### Moving forward
The next step is yet another software rewrite; this one is going to be a little more intense than the previous ones, because it has to support more on the built-in web app side: scale calibration, including zero point and calibrated mass, equipment-weight setting, tare, and the like. It also has to take a starting gravity and start time when starting a batch, so it can calculate volume and save the start weight for future delta calculations.

I also have to set up a mechanism for selecting which of up to two temperature sensors is for wort, and which is for load cell compensation, but that'll come later. My aim at present, with the scale finished, is to do the following:

1. Build a scale in software, with functions for saving the zero point and calibrating with a given mass.
2. Build the batch-initial data stuff.
3. Implement Balling's-numbers calculation for offgassing.
4. Run a test fermentation.

I can readily do a half-gallon test fermentation, and may be able to do a 1-gallon test fermentation. In the former case, I'd expect a fairly wobbly line; the required resolution there is about 1.9 grams per gravity point. In the latter case, it's 3.8 grams, which should be pretty close to on point. I've borrowed the refractometer from the homebrew shelf in my buddy's utility room, so I'm pretty much set to go.

### Circuit board changes
My first prototype circuit boards should, as I keep on saying, arrive in the next week or so. I think I want to try my hand at assembling one, even though the design has changed (both because of the battery change and the move to the scale). That should give me an idea for how easy it is.

The new PCB design is pictured below.

pcb

Removing the battery circuitry and breakout board makes for a much cleaner design, and a moderate reduction in component count. That'll make professional assembly cheaper and DIY assembly easier.

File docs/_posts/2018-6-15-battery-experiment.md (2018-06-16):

---
layout: post
title: Benchtop experiment results and a PCB update
---

A pendulum in the configuration called out in the main README has been running on my workbench for the past 10 days. Below are some graphs of interest.

gravity-temperature

Here we have the gravity and temperature graph. Obviously, the gravity doesn't correspond to any actual fermentation. I just tipped it a little bit further every now and then through most of the experiment.

The gravity readings are remarkably stable for a given angle. I'm averaging the values from the MPU for quite a long time, which presumably helps, but I'll want to test to find out how much I have to do before I get into the region of diminishing returns. Every little bit helps.

Some testing with a separate thermometer has revealed the MPU6050 temperature sensor to be accurate at first, but to gain a few degrees Fahrenheit over the first few minutes the chip is powered on. To counteract this, pendulum takes the temperature samples first in hydrometer mode, and only powers the MPU6050 on for long enough to take a measurement in hotspot mode. In using the MPU6050 temperature sensor, we forego the separate sensor used by the iSpindel project.

Unrelatedly, the temperature graph provides an interesting record of temperature fluctuations in my basement. The steep gradients happen when the air conditioner runs.

battery

News on the battery front is a little less positive. On a 2600mAh battery of uncertain age (I salvaged it from a project at work), this pendulum lasted 248 hours. Averaged over the whole experiment, that's a power draw of 10.5mA. Not great.

It turns out, though, that most of the draw comes from the voltage regulator on the Wemos board. The AMS1117 chip on the board, according to its datasheet, draws a typical quiescent current of 5mA, and a maximum of 11mA. In the best-case scenario, the voltage regulator accounts for half our voltage draw. In the worst case, it accounts for all of it.

The truth probably lies somewhere in between. The ESP8266 draws about 35mA when awake and connected to wifi, with transients of 400mA on startup and 250mA on wifi radio activity. Let's just take 250mA as the average power-on draw, and assume it's awake for 10 seconds every half hour. Both of those assumptions are on the too-pessimistic side, note; the average consumption is most likely in between 35mA and 250mA, and observations suggest it's awake for more like 5 to 8 seconds.

Still, I don't want to get my hopes up too much. 250mA for 10 seconds is about 0.7mAh, and 496 half-hourly wake-ups is 344mAh.

We can account for the sleep current, too. The ESP8266 datasheet claims it draws 10 microamps in deep sleep. Let's round up to 100µA, for leakage current across capacitors and so on. 496 10-second wakeups makes for a bit over 82 minutes, which comes to about 246 hours and 40 minutes of sleep time. 100µA over 246 hours is a bit under 25mAh.

So, total power consumption by the actual parts we're concerned with looks to account for about 15% of the power consumption during this experiment, and the voltage regulator for the remaining 85%.

For comparison, the MCP1700 I call for in the PCB design draws between 1 and 5 microamps, about 1000 times less than the AMS1117. Even taking my conservative numbers as gospel, that takes us to a battery life of about 1600 hours with half-hourly samples, or about two months. Unlike today, where most of the consumption happens during sleep mode, most of the consumption with a lower-quiescent-current regulator happens during samples, so the battery life can be extended almost indefinitely by lower sample rates.

pcb

Now that the custom PCB is looking like the way to go, I've done some cleanup work on the design. I'm still terrible at this circuitry thing, as evidenced by the fact that the first schematic called for a capacitor in series with the rest of the circuit. Recent versions fix that for the regulator output capacitor, add a regulator input capacitor, and add a smoothing capacitor across the ESP8266 V+ and GND.

I also did some cleanup of the traces, improved the readability of the labeling, and rerouted some traces near the ESP-12. For one, nothing runs beneath the antenna anymore, and the GY-521 signal lines go on the underside of the board, rather than directly beneath the ESP-12, which should reduce interference.

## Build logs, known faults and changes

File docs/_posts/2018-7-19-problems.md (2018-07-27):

---
layout: post
title: Design issues and proposed solutions
---

## Problems
My 200-gram load cell recently arrived, so I figured I'd sit down and build a Pendulum stopper assembly to see how it works.

As the heading suggests, I ran into some trouble.

### Rubber is springy
Shocker, I know. Rubber stoppers are, as it turns out, much springier than load cells, so loading the stopper assembly with a torque force mostly ends up applying the force to the stopper itself, rather than the load cell where we want it.

In practice, this means that the load cell readings are worth pretty much nothing; they're overwhelmed by the confounding factors.

### The stopper assembly is crowded
My little test chamber is a half-gallon milk jug. Getting the sinker and the temperature sensor in is proving to be a bit of a pain. This is, in part, because the sinker is quite tall compared to the milk jug, so the line connecting it to the load cell is quite short. In part, it's because a 27mm cylinder and a 3-4mm wire are hard to maneuver together.

### A three-hole stopper is hard to make
To build a Pendulum properly, you need three holes in a stopper: one for the airlock, about 3/8" diameter; one for the temperature sensor, about 1/4" diameter, and one for the load cell assembly, a little smaller than 1/4" diameter. That may be a tall order to fit into a standard #6.5 or #7 stopper.

## Solutions
Of course, there are ways to fix these problems, some more dramatic than others.

### A stopper topper
Cut a disc of plywood about the size of the top of a stopper. Drill three holes aligned with the holes in a Pendulum three-hole stopper. Glue the topper to the stopper, and affix the load cell hanging arm to the topper rather than the stopper. Plywood is much less bendy than rubber, and should be sufficiently supportive.

This option requires very little extra work, and all I have to do to test it is buy a hole saw and some drill bits, which I want anyway. It may have some function issues, and does tie kitbuilders more closely to a stopper of a certain size and design.

### A through-the-airlock load cell
It occurs to me that a weight hanging through an S-type airlock should still apply force to a load cell outside the airlock. Moving the load cell outside solves the moisture problem and likely the temperature sensitivity problem, because it 1) is away from the area where there's the greatest risk of moisture and 2) can be mounted in the traditional, horizontal orientation. In that orientation, the load cell's output voltage is much greater, because the shear strain on the gauge is also much greater.

On the other hand, it requires building some sort of outside-the-carboy tower to hold the load cell. That's not necessarily a simple engineering endeavor. This concept also depends on tension being transmitted through the airlock in a reasonable, linear fashion, which is not necessarily guaranteed. I'll be testing this after bottling day.

### A beer scale
Eagle-eyed observers might have noted the appearance of a 'Libra Cervisiae' folder in the repository. I've been thinking about it, and this idea has some serious merit. It's universal, it doesn't require any complicated engineering or very complicated assembly, and it's also not, to the best of my knowledge, patented or patent-pending.

So, you have a scale. Tare it so that it reads zero with your fermentation vessel and airlock resting on it. Fill your fermentation vessel with wort and provide an initial gravity reading. Now you know the precise volume of beer in your fermenter: you've provided a density, and the scale reads the weight of the wort.

Take weight readings over time. As the beer ferments, yeast turns sugar into alcohol, more yeast, and carbon dioxide. Karl Balling tells us the ratio: 2.0665 grams of sugar turn into 1 gram of ethanol, 0.11 grams of yeast biomass, and 0.9565 grams of carbon dioxide. Put another way, the beer gets 0.9565 grams lighter for every gram of alcohol produced.

Looking at it from another direction, the difference between (say) 19 liters of beer at 1.015 SG and 1.016 SG is about 19 grams (four US nickels, or two 2-euro coins). That's an easy difference to measure on a 20kg scale—about 0.1%, when load cell errors are on the order of 0.01%.

As further support for this idea, [it's already been done](https://www.homebrewtalk.com/forum/threads/estimating-alcohol-by-total-weight-during-fermentation.265716/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).

I spent some time knocking together a slightly modified PCB design, which ditches the solder-on pads in favor of connectors for everything, and adds three more load cell connectors:

nu-pcb

The benefits to this approach are several: as I said, it's universal, and the engineering is simple. It provides a precise reading on pre-fermentation volume, and can probably be used to work out current volume, too. It's also easy to scale up: if you're doing 10-gallon batches, build for 40kg capacity; the error is twice as much, but the sensitivity requirements are halved, as the change in mass in your beer is twice as large. You don't need a custom stopper; anything with a thermowell and a hole for your airlock suffices.

There are, of course, problems. Load cell creep is likely to play a much larger role. It's also more expensive—load cells are the expensive component in the torpedo method, and this needs four rather than one. It also calls for a bunch of difficult-to-ship materials: as much as four feet by two feet of plywood, for a two-foot by two-foot scale, and thirty-some nuts and bolts to tie everything together. I'd have to find two-meter temperature sensors to go from the controller up to the top of the fermentation vessel and back down.

Lastly, the cost per example shoots up to $25 or so from $15, and that's ignoring the cost of plywood for the scale surfaces. (There's probably a reasonable way to hack a Libra Cervisiae PCB into, say, a bathroom scale or shipping scale, however. That might be worth investigating.)

Still, though, I think the benefits outweigh the drawbacks. Simplicity is golden, and this has simplicity to spare.

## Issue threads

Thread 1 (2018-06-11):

Question:

thelonecabbage, 2018-06-11:
Is the battery required to be a flat top?

Why do the calculations on the pendulum?  Why not send the raw data back to the server?

thelonecabbage, 2018-06-11:
BTW: very interested in this project.  very cool.

jslater89, 2018-06-11:
For some reason I remembered reading on Amazon that the slot was for flat tops, but the contacts in the battery slot are sufficiently springy that I don't think flat top is a requirement. I don't have any button-top batteries to test with, though.

I'm doing the calculations on the device primarily with an eye toward supporting alternate endpoints—if people want to integrate it into pre-existing systems, it helps to have all the data already figured out.

Closed 2018-06-11.

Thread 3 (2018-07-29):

Improve sensor startup behavior

jslater89, 2018-07-29:
Both sensors need some warmup time to either come online (DS18xxx) or stabilize (HX711). Separate the pre-delay and post-delay startup for each sensor, and provide an initSensor function to do the pre-delay/delay/post-delay cycle correctly.

jslater89, 2018-07-30:
Finished.

Closed 2018-07-30.

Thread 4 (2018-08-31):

HX711 reads over more than 1-2 seconds change the output value

jslater89, 2018-08-31:
Noise? Coupling? Something else?

We'll see if the 0.2.0 boards show it, then go from there.

jslater89, 2018-09-03:
Solved, for obvious reasons: if you don't connect a load cell, the HX711 doesn't really know what to do with itself. With a load cell connected, everything is fine.

Closed 2018-09-03.

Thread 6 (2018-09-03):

GroovyLogger enhancements: CLI

jslater89, 2018-09-03:
Command-line interface to select local address to poll, read interval, and output destinations.

jslater89, 2019-08-08:
GroovyLogger enhancements aren't needed thanks to the ESP32 switch, but this one would be nice to have anyway.

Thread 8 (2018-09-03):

GroovyLogger enhancements: server mode

jslater89, 2018-09-03:
Run a little tiny HTTP server of some kind, so that a Libra Cervisiae in hydrometer mode can wake up and push updates.

jslater89, 2019-08-08:
wontfix: ESP32 switch means GroovyLogger can remain a development tool

Closed 2019-08-08.

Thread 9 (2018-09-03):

Investigate double reset failures

jslater89, 2018-09-03:

jslater89, 2019-08-19:
Closing this one, because I have to do a double reset detector for the ESP32 anyway.

Closed 2019-08-19.

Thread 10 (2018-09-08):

Fritzing diagram for breadboard/ESP module version

jslater89, 2018-09-08:
The software is basically ready to support a breadboard circuit. Whip up a little Fritzing diagram to indicate how such a circuit should be wired, including four load cells and two temperature sensors, so that enthusiastic DIYers don't have to wait for the slightly more productized kits/prebuilt versions.

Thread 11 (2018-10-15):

Solve multiple load cell scale problems

jslater89, 2018-10-15:
See 10/14 blog post.

jslater89, 2019-08-08:
Appears to be solved: bad connector assembly. See today's blog post.

Will close when verified.

jslater89, 2019-08-11:
Verified!

Closed 2019-08-11.

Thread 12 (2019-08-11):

Convert firmware to ESP32

jslater89, 2019-08-11:

jslater89, 2019-09-03:
The blocker on this one is replacing DoubleResetDetector for the ESP32, which may not be readily attainable given how RTC memory works on the ESP32.

If not, it'll require a circuit change—add a third button to hold to do 'reboot into hotspot mode'.

jslater89, 2019-09-09:
DoubleResetDetector doesn't appear to be feasible—pulling EN low resets the RTC, too, so no data can survive.

Closed 2019-09-09.

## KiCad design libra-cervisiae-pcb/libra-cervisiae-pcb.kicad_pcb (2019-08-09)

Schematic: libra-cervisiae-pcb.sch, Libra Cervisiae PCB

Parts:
C1, C4, C5: 100nF; C_0805_2012Metric
C2, C6, C7, C8: 1uF; C_0805_2012Metric
C3: 47uF; C_0805_2012Metric
CN1: CP2102-BREAKOUT
CN2: HX711_BREAKOUT; HX711-MINI
J1: Wort Temp; PinHeader_1x03_P2.54mm_Vertical
J2: Ambient Temp; PinHeader_1x03_P2.54mm_Vertical
J3: Load Cells; PinHeader_2x08_P2.54mm_Vertical
R1, R3, R4, R5, R6: 10k; R_0805_2012Metric
R2: 2.2k; R_0805_2012Metric
SW1: Reset; 4x3_Switch
SW2: Flash; 4x3_Switch
U1: ESP-12F; ESP-12E
U2: VREG; SOT-23

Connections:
/3.3+: C3.1, C4.1, C8.2, R1.1, R3.2, R4.1, R6.1, U1.8 (VCC), U2.2 (VO)
/CLK: CN2.9, U1.14 (GPIO5)
/DAT: CN2.8, U1.13 (GPIO4)
/DS+: C2.2, J1.3, J2.3, R2.2, U1.5 (GPIO14)
/DSD: J1.2, J2.2, R2.1, U1.6 (GPIO12)
/E+: CN2.1, J3.1, J3.5, J3.9, J3.13
/E-: CN2.2, J3.2, J3.6, J3.10, J3.14
/FLASH: R6.2, SW2.1, U1.12 (GPIO0)
/GND: C1.1, C2.1, C3.2, C4.2, C5.1, C6.1, C7.1, C8.1, CN1.5, CN2.10, J1.1, J2.1, R5.1, SW1.2, SW2.2, U1.9 (GND), U2.1 (GND)
/HostRX: CN1.3, U1.16 (TXD)
/HostTX: CN1.4, U1.15 (RXD)
/RST: R1.2, SW1.1, U1.1 (REST), U1.4 (GPIO16)
/S+: CN2.4, J3.4, J3.8, J3.12, J3.16
/S-: CN2.3, J3.3, J3.7, J3.11, J3.15
/USB+: C1.2, C5.2, C6.2, C7.2, CN1.6, CN2.7, U2.3 (VI)
unnamed: R3.1, U1.3 (CH_PD)
unnamed: R4.2, U1.11 (GPIO2)
unnamed: R5.2, U1.10 (GPIO15)

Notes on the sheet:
MCP1700
Load Cells
DS18B20s

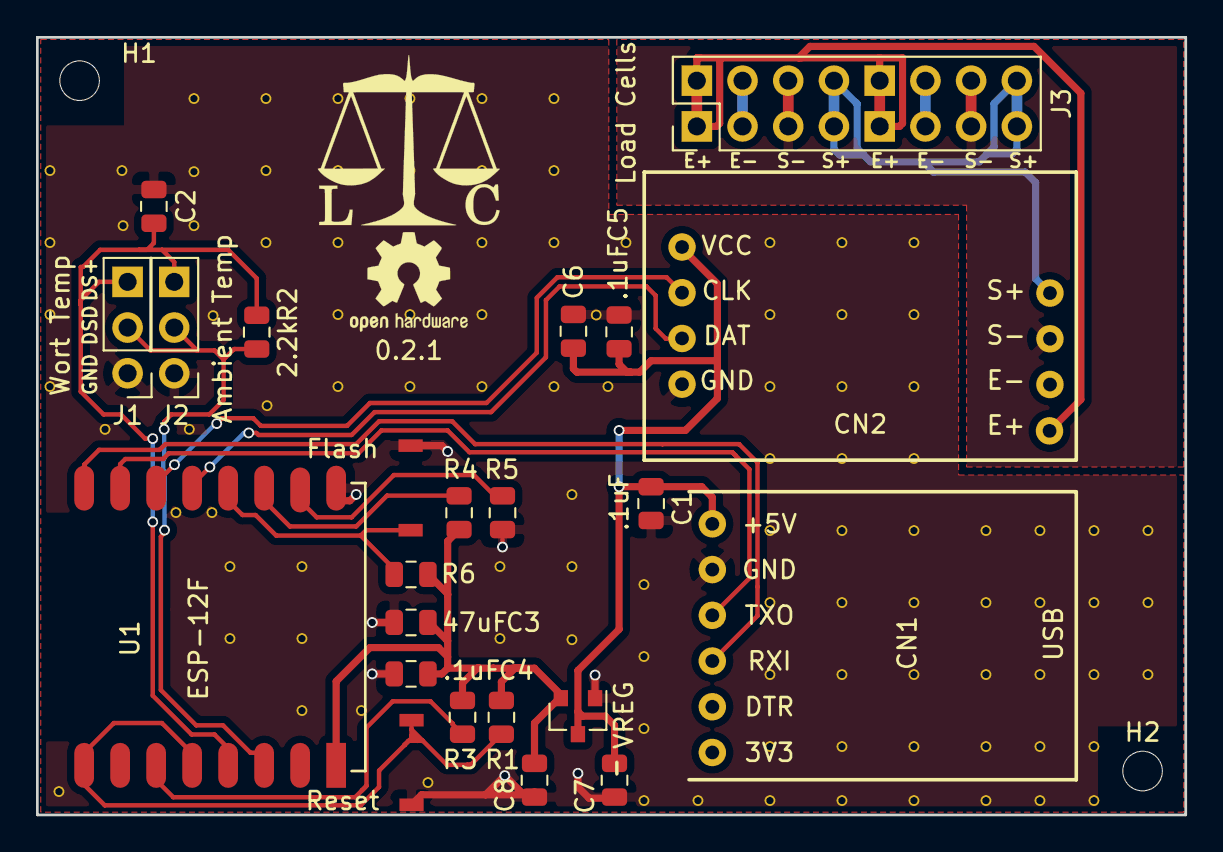
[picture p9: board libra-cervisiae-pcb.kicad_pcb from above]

Board: 2 copper layers, 63.8 x 43.2 mm, 25 parts (0 on the bottom side), 18 nets.

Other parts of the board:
H1, H2: MountingHole_2.2mm_M2

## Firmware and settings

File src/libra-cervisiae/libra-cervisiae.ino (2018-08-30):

#include <ESP8266WiFi.h>
#include <FS.h>
#include <pgmspace.h>
#include "libra-cervisiae.h"
#include "config.h"
#include "hotspot.h"
#include "hydrometer.h"
#include "sensors.h"

/**
 * LIBRA CERVISIAE is a scale controller for homebrewing use.
 * 
 */

DoubleResetDetector drd(5 /* timeout */, 0 /* address */);
long bootMillis;
boolean tareInProgress = false;
boolean calibrationInProgress = false;

boolean hotspotMode;

void setup() {
  bootMillis = millis();
  Serial.begin(115200);

  Serial.println();
  Serial.println(F("Libra Cervisiae powered on"));

  WiFi.disconnect(); // disconnect to avoid stomping on other operations
  WiFi.persistent(false); // don't write to flash

  // start filesystem
  boolean result = SPIFFS.begin();
  if(!result) {
    Serial.println(F("Unable to start SPIFFS"));
  }

  // read in config
  result = loadConfig();
  if(!result) {
    Serial.println(F("Unable to load configuration"));
  }
  printConfig();

  if(DEBUG_TIMINGS) {
    Serial.print(F("Config loaded: ")); Serial.println(millis() - bootMillis);
  }

  initSensors();

  hotspotMode = true; //bootToHotspot || !result | drd.detectDoubleReset();

  if(DEBUG_TIMINGS) {
    Serial.print(F("Startup finished: ")); Serial.println(millis() - bootMillis);
  }

  // enter hotspot mode if there's no network configured
  if(hotspotMode || strcmp(wifiNetwork, "your_ssid") == 0) {
    Serial.println(F("Hotspot mode selected"));
    hotspotSetup();
  }
  else {
    Serial.println(F("Hydrometer mode selected"));
    hydrometerSetup();
  }
}

void loop() {
  if(hotspotMode) {
    hotspotLoop();
  }
  else {
    hydrometerLoop();
  }
}

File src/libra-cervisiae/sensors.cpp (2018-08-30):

#include <pgmspace.h>
#include "libra-cervisiae.h"
#include "sensors.h"
#include "temperature.h"
#include "scale.h"

// one-time sensor init
void initSensors() {
  initScale();

  if(DEBUG_TIMINGS) {
    Serial.print(F("Scale init done: ")); Serial.println(millis() - bootMillis);
  }
  
  initTemp();

  if(DEBUG_TIMINGS) {
    Serial.print(F("Temp init done: ")); Serial.println(millis() - bootMillis);
  }
}

void sensorsPreDelay() {
  scaleStart();
}

void sensorsPostDelay() {
  tempStart();
}

// start sensors after shutdown
void startSensors() {
  sensorsPreDelay();

  if(DEBUG_TIMINGS) {
    Serial.print(F("Sensors pre-delay: ")); Serial.println(millis() - bootMillis);
  }
  
  delay(500);

  sensorsPostDelay();

  if(DEBUG_TIMINGS) {
    Serial.print(F("Sensors post-delay: ")); Serial.println(millis() - bootMillis);
  }
}

// shutdown sensors after startup
void stopSensors() {
  scaleStop();
}

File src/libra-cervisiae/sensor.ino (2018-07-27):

#ifdef WEMOS
#define DS18B20_POWER_PIN 12
#define DS18B20_DATA_PIN 13

#elif defined PCB
#define DS18B20_POWER_PIN 12
#define DS18B20_DATA_PIN 13

#elif defined NODEMCU
#define DS18B20_POWER_PIN 12
#define DS18B20_DATA_PIN 13

#endif

OneWire oneWire(DS18B20_DATA_PIN);
DallasTemperature sensors(&oneWire);

void tempSetup() {
  //DS18B20
  pinMode(DS18B20_POWER_PIN, OUTPUT);
  digitalWrite(DS18B20_POWER_PIN, HIGH);
  
  sensors.begin();
  sensors.setResolution(12);

  delay(500);
}

void tempShutdown() {
  digitalWrite(DS18B20_POWER_PIN, LOW);
}

// Get temperature from wort sensor
// returns Fahrenheit temperature
void readWortTemp(double* t) {
  sensors.requestTemperaturesByAddress(&wortTempAddr);

  // 12-bit temperature takes 750ms. Delay so the ESP can do its thing
  // while we wait.
  delay(750);
  *t = sensors.getTempF(&wortTempAddr);
}

// Get temperature from board sensor
// returns Fahrenheit temperature
void readBoardTemp(double* t) {
  sensors.requestTemperaturesByAddress(&boardTempAddr);

  // 12-bit temperature takes 750ms. Delay so the ESP can do its thing
  // while we wait.
  delay(750);
  *t = sensors.getTempF(&boardTempAddr);
}

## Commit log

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2018-06-03 Config/Calibration handling, double-reset mode selection
    [config.ino, hotspot.ino, hydrometer.ino]
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2018-06-06 Add output, API config, fix wifi reconnection
    [config.ino, hotspot.ino, hydrometer.ino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]
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2018-06-14 A custom PCB is probably the best solution in the long run...
    ... so I went ahead and figured one out. Obviously not worth messing
    around with until I've done the whole thing on a breadboard.
    [pcb.kicad_pcb, pcb.sch]
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2018-06-14 Move a resistor to line up with another resistor
    [pcb.kicad_pcb]
2018-06-14 Correct GY521 dimensions
    [pcb.kicad_pcb]
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2018-06-15 Remove traces under ESP-12 antenna, switch to 90* Molex connector
    [pcb.kicad_pcb, pcb.sch]
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2018-06-15 Tweak switch silkscreen labels, add polarity sign to capacitor
    The MCP1700 says a ceramic capacitor is fine, but in case people use
    polar capacitors, it's nice to have an indicator of which way it goes.
    For the switches, remove the redundant SW1/2 label beneath Flash/Reset,
    and just label inside the switch footprint.
    [pcb.kicad_pcb]
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2018-06-15 Route I2C traces on opposite side of PCB from ESP-12
    Hopefully to limit interference.
    [pcb.kicad_pcb]
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2018-06-15 Fix problems from Capacitors 101
    [pcb.kicad_pcb, pcb.sch]
2018-06-16 Move label, update parts shopping list with more parts
    [pcb.kicad_pcb]
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2018-06-16 PCB: use a smaller FTDI breakout board
    The CP2102 USB Micro breakout boards look like they fit between the
    pins of the TP4056 breakout board, which simplifies installation.
    [pcb.kicad_pcb, pcb.sch]
2018-06-17 Some more minor touch-ups
    1. Remove silkscreen from pads which will take soldering
    2. Fix some trace-via clearance issues (min 5 mil)
    [pcb.kicad_pcb, pcb.sch]
2018-06-17 More trace cleanup:
    1. Remove right angles
    2. Thicker USB+/-, charger +/-, 3.3, GND traces
    3. Improve 3.3 and GND routing: more like rails and traces to
    components, less daisy-chaining
    [pcb.kicad_pcb]
2018-06-17 GY521 dimensions update (to match measured size on my workbench)
    [pcb.kicad_pcb]
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2018-06-18 Some significant design changes
    Thanks to u/Triabolical_ and u/alez from r/PrintedCircuitBoards for their
    feedback and advice.
    1. Switch to 805 resistors and the non-hand-soldered PCB pad footprints
    They're not appreciably harder to solder, given that they're only 0.01"
    smaller than the 1206 size, and they make routing considerably easier.
    The non-hand-soldered size will be a bit trickier, but not all that
    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
    [pcb.kicad_pcb, pcb.sch]
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2018-06-18 Flip USB-to-serial board so that USB port points outward
    [pcb.kicad_pcb]
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2018-06-20 Patent-unencumbered PCB concept
    Tilting is off the table, so let's explore a different idea: weighing
    a sinker immersed in the wort. See the github pages plog for more.
    [pcb.kicad_pcb, pcb.sch]
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2018-06-20 Fix unconnected pad, oops
    [pcb.kicad_pcb]
2018-06-20 Add a pad for a decoupling capacitor for temperature sensor, just in case
    [pcb.kicad_pcb, pcb.sch]
2018-06-20 Measure some pictures of chips to update local parts libraries
    Hopefully it's good enough. Otherwise we'll fix it in rev2.
    [pcb.kicad_pcb, pcb.sch]
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2018-06-21 Fix some design errors, including a missing connection from 16->RST
    [pcb.kicad_pcb, pcb.sch]
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2018-06-21 Switch to p-channel MOSFET for battery monitor switch
    Because we want as close to zero voltage through the circuit to the
    ADC as possible when the battery monitor is off and the temperature
    sensor is on, we need to switch on the high side, between BAT+ and
    ADC.
    The BSS84 seems like a reasonable choice; its maximum gate threshold
    voltage is well below the difference between ground and a discharged
    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
    [pcb.kicad_pcb, pcb.sch]
2018-06-22 DS18B20, 4x3 switch footprint, routing tweaks
    Use a DS18B20 temperature sensor instead of a TMP36. We have enough
    GPIOs—we can drive it from the former SENS2 net (power for the prior
    sensor) and use the former SENS1 net (battery monitor transistor) for
    the data line. This simplifies the ADC circuitry significantly, and
    lets us ditch a bunch of parts.
    Add 4mmx3mm switch footprint, adjust routing as needed.
    [pcb.kicad_pcb, pcb.sch]
2018-06-24 Add capacitors across TP4056 OUT+/OUT-
    I'm told this will fake a battery sufficiently well to keep from
    confusing the TP4056 in the no-battery case. The two 47uF capacitors
    can run the whole PCB in sleep mode for 2-3 seconds, and presumably
    the non-sleep-mode load is sufficient to fool the TP4056.
    I guess we'll see!
    [pcb.kicad_pcb, pcb.sch]
2018-06-24 Another crack at a battery disconnector circuit
    I found an example on the Arduino forums (link at end). It uses a
    p-channel MOSFET 'backwards', with source connected to the load
    and drain to the battery. The parasitic diode therefore blocks
    leakage back into the battery. USB is connected to the gate and also
    to the load, the latter via Schottky diode, to prevent battery
    voltage from sneaking back through the circuit to flip the MOSFET.
    A large capacitor buffers between the voltage regulator and ground,
    to ensure that the system doesn't lose power while things are switching.
    (The MOSFET takes on the order of nanoseconds to switch; the 47uF
    capacitor between VREG+ and GND can run the ESP at p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
    [pcb.kicad_pcb, pcb.sch]
2018-06-25 Switch to 1206 footprint for Schottky diode; 0805 seems hard to find
    At least at the rated power we need (up to about 500ma).
    [pcb.kicad_pcb, pcb.sch]
2018-06-25 Use correct diode SMD package (DO-214AC/SMA)
    That's the package all the high-power ones seem to come in.
    [pcb.kicad_pcb, pcb.sch]
2018-06-25 Fix unconnected pad
    [pcb.kicad_pcb]
2018-06-26 pcb-1.0.0-rc.4
    Just a few final tweaks—labeling, adding a capacitor across USB
    in for filtering.
    [pcb.kicad_pcb, pcb.sch]
2018-06-26 More capacitance! More ground pour!
    Per recommendations. The ADC trace is long and very low-current,
    and needs some smoothing for EMI reasons. The ground pour is bigger
    to reduce the number of long traces to ground.
    [pcb.kicad_pcb, pcb.sch]
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2018-06-28 Bite the bullet and go to a full-backside ground pour
    This also involves removing some unnecessary vias and traces
    routed on the back of the board. Where possible, power and signal
    lines run over ground pour.
    [pcb.kicad_pcb]
2018-06-28 Some further bottom trace reductions
    Break up some islands in the pour so that the return paths are
    closer to the traces.
    [pcb.kicad_pcb]
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2018-07-04 Add 3D models for headers, connectors, and buttons
    Not for the boards, but those aren't as trivial as just picking
    3D models for the various footprints here.
    [pcb.kicad_pcb]
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2018-07-04 Labeling changes
    In particular, put the diode model number in the schematic and on
    the board.
    [pcb.kicad_pcb, pcb.sch]
2018-07-06 Fix HX711 footprint (part 1)
    I have a few on hand now, so I can also do actual measurements.
    Once I borrow some calipers again, anyway.
    [pcb.kicad_pcb]
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2018-07-07 Add a 10k pullup resistor to DSD/DS+
    Testing reveals that such a thing is needed.
    [pcb.kicad_pcb, pcb.sch]
2018-07-08 Debug timings, hotspot mode live data tweak
    Debug option to print out timings while running in hydrometer
    mode.
    Hotspot mode live data no longer reads sensors on request;
    instead, it reads ~once per read interval, and reports cached
    data. (This saves on processing time. The reads take a long
    time.)
    [hotspot.ino, hydrometer.ino, output.ino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]
2018-07-09 Switch to DoubleMatrixMath
    DoubleMatrixMath is a copy of the MatrixMath library which replaces
    floats with doubles, for use on platforms where double is higher-
    precision than float. (Such as the ESP8266.) Uploading that to
    Github soon.
    [hotspot.ino]
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2018-07-09 More config options: API path, boot to hotspot, output mode
    API path: for path-sensitive APIs, a path to append to the
    API root.
    Boot to hotspot: skip hydrometer mode altogether.
    Output mode: 0 for nothing, 1 for Graviton, others for
    other outputs.
    [config.ino, hotspot.ino, hydrometer.ino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]
2018-07-11 Temperature compensation config, live webpage bugfixes
    [config.ino, hydrometer.ino]
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2018-07-20 Libra Cervisiae: add a temperature sensor to the board
    Optional, but recommended: can be used to correct load cell
    output for ambient temperature changes.
    [libra-cervisiae-pcb.kicad_pcb, libra-cervisiae-pcb.sch]
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2018-07-27 Fix tare, very rough crack at actual scale output
    [hotspot.ino, hydrometer.ino, scale.ino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]
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2018-07-29 Calibration stuff, temperature sensors part 1
    1. Calibration: fix some bugs
    2. Temperature sensors: handle addresses correctly
    Still to do: saving and restoring addresses correctly
    [config.ino, hotspot.ino, hydrometer.ino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]
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2018-07-30 Fix bug in temperature sensor output
    [hotspot.ino]
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2018-08-01 Fix board/wort sensor selection
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2018-08-02 Final fixes for temperature compensation and batch starting
    [hotspot.ino, hydrometer.ino]
2018-08-02 Fix temperature correction sign
    [scale.ino]
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2018-08-08 Fix fermentation math
    Previously, I was taking the weight delta as the amount of fermented
    sugar. The weight delta is actually the amount of CO2 offgassing;
    the mass of fermented sugar is (1 / co2PerGramFermented).
    [hydrometer.ino]
2018-08-08 Make mounting holes and stitching vias virtual footprints
    That way they don't show up in the BOM, which is also updated.
    [libra-cervisiae-pcb.kicad_pcb]
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2018-08-10 Fix repeated tares, calibrations
    Forgot to reset the average-steps variable.
    [scale.ino]
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2018-08-16 Fix some perilously dumb pointer use
    [hotspot.ino]
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2018-08-30 Some fixes to the on-device web stuff, based on testing
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2018-08-31 Switch to pin headers/dupont connectors
    The wee JST things I bought are next to impossible to do without
    specialized tools.
    [libra-cervisiae-pcb.kicad_pcb, libra-cervisiae-pcb.sch]
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2018-09-13 Fix some labeling alignment
    [libra-cervisiae-pcb.kicad_pcb]
2019-04-05 Rejigger the load cell e+/s+ traces for approximately equal length
    Is that important? Beats me, but it's worth a shot.
    [libra-cervisiae-pcb.kicad_pcb]
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
